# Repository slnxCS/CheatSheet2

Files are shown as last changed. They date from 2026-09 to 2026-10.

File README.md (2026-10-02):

# CheatSheet2

**[English](README.en.md)** · 🇷🇺 Русский

## О проекте

Портативное устройство на **ESP32-S3-N16R8 CAM** с цветным дисплеем, камерой и 5 кнопками управления

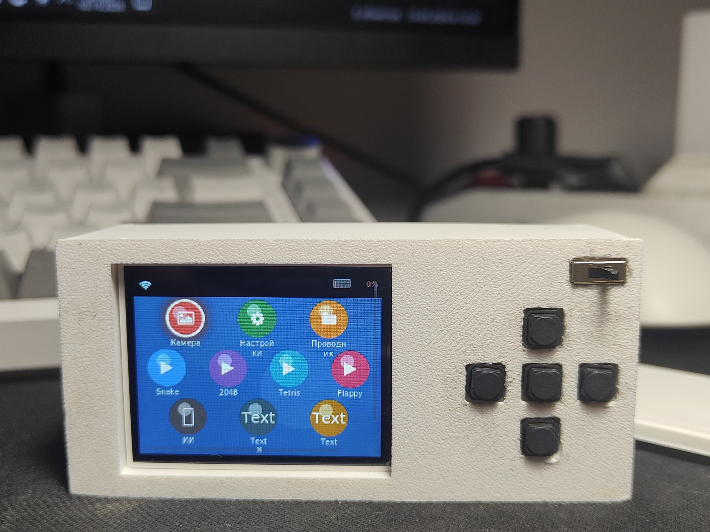
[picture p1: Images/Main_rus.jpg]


## ⚡ Возможности

 - Удобное управление с телефона с помощью приложения
 - Помещается в пенал
 - Бесшумные кнопки
 - Хорошо читаемый русский/английский текст
 - Много игр (Змейка, 2048, тетрис, flappy bird)
 - Большой дисплей
 - Камера
 - ИИ-агент (для работы нужно подключение с телефона), которому можно отправлять фото

## 🛠️ Сборка

### Необходимые компоненты

| Компонент | Кол-во | Ссылка для покупки (проверено для РФ) |
|---|:---:|---|
| ESP32-S3-CAM N16R8 (подойдёт любая камера, в проекте OV5640) | 1 | https://ali.click/lftxm1n |
| Любой аккумулятор | 1 | https://ozon.ru/t/T2QhKQN |
| TP4056 | 1 | https://ali.click/8ktxm18 |
| Бустер напряжения MT3608 | 1 | https://ali.click/9mtxm1z |
| TFT-дисплей 2.0" 320x240 ST7789 | 1 | https://ali.click/vntxm1e |
| Бесшумные кнопки | 3 | https://ali.click/fotxm1k |
| Тумблер питания | 1 | https://ali.click/crtxm11 |
| Резистор 10 кОм | 2 | https://ali.click/f9uxm1h |

## 🔌 Схема подключения

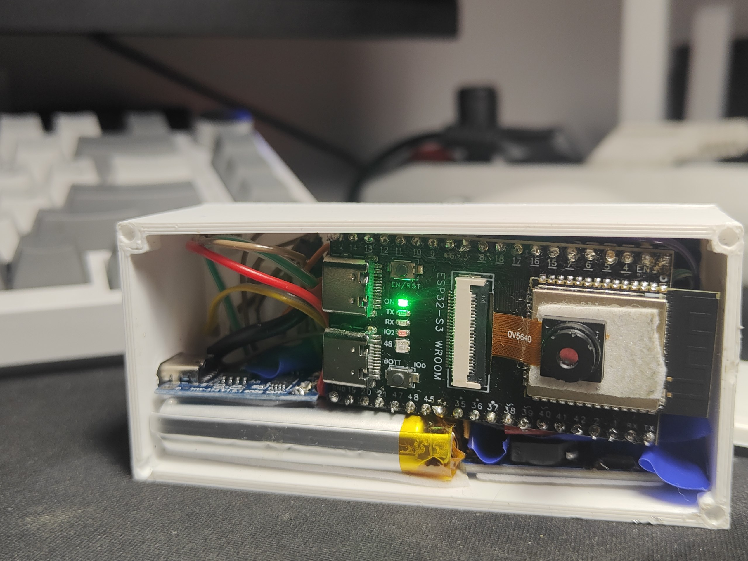
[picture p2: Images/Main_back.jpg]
BackView


| Модуль | Пин | Пин | Пин | Пин | Пин | Пин | Пин |
|---|-----|-----|-----|-----|-----|-----|-----|
| **🔋 Аккумулятор** | +(красный провод) → TP4056 bat + | -(чёрный провод) → TP4056 bat - | - | - | - | - | - |
| **🔋 TP4056** | Out + → центральная ножка переключателя (свитча) + | Out - → VIN - (повышайка напряжения MT3608) | Out + → резистор 10 кОм → ESP GPIO0 → резистор 10 кОм → ESP GND (-) | - | - | - | - |
| **Выключатель** | Правая ножка переключателя → VIN + (повышайка напряжения MT3608) | - | - | - | - | - | - |
| **MT3608 (бустер напряжения)** | VOUT(+) → ESP 5V | VOUT(-) → ESP GND | - | - | - | - | - |
| **Дисплей** | VCC(+) → ESP32 3.3V | GND(-) → ESP32 GND | SCLK (SCL) → ESP GPIO 41 | MOSI (SDA) → ESP GPIO 42 | CS → ESP GPIO 47 | DC → ESP GPIO 46 | RST → ESP32 3.3V |
| **Кнопки** (⚠️ 1 ножка каждой кнопки — на ESP GND) | Левая → GPIO 14 | Правая → GPIO 45 | Верхняя → GPIO 1 | Нижняя → GPIO 2 | OK → GPIO 21 | - | - |

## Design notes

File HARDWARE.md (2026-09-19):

# CheatSheet2 — Схема подключения

## Плата: ESP32-S3-N16R8 CAM (OV5640)

---

### Занятые GPIO (НЕЛЬЗЯ использовать)

```
┌────────────────────────────────────────────────────────┐
│ GPIO 0      — BOOT (strapping)                        │
│ GPIO 4-13   — Камера DVP (фирксована на плате)       │
│ GPIO 15-18  — Камера DVP                             │
│ GPIO 19-20  — USB D-/D+                               │
│ GPIO 26-32  — Flash SPI (internal)                    │
│ GPIO 33-37  — Octal PSRAM (8MB OPI)                  │
│ GPIO 38-40  — SD-карта (распаяна на плате)           │
│ GPIO 48     — WS2812 RGB LED (на некоторых платах)   │
└────────────────────────────────────────────────────────┘
```

---

### TFT 2.0" ST7789 240x320 (SPI)

```
┌─────────────────┐          ┌──────────────────────────┐
│   ST7789 TFT    │          │  ESP32-S3-N16R8 CAM      │
│                 │          │                          │
│  VCC  ──────────┼──────────┼── 3V3                    │
│  GND  ──────────┼──────────┼── GND                    │
│  MOSI ──────────┼──────────┼── GPIO 42                │
│  SCLK──────────┼──────────┼── GPIO 41                │
│  CS   ──────────┼──────────┼── GPIO 47                │
│  DC   ──────────┼──────────┼── GPIO 46                │
│  RST  ──────────┼── 3.3V   │  ( pull-up 10k к 3.3V ) │
│  BL   ──────────┼──────────┼── GPIO 45                │
│  MISO ──────────┼── (NC)   │  (не подключается)       │
└─────────────────┘          └──────────────────────────┘

ВАЖНО: RST не подключается к ESP32!
Подключите RST к 3.3V через подтягивающий резистор 10kОм.
Это освобождает GPIO для кнопок.
```

**Частота SPI**: 80 МГц
**Примечание**: MISO не используется — ST7789 только на запись

---

### Кнопки (5 шт, крестовина + OK)

```
┌───────────────┐          ┌──────────────────────────┐
│   Кнопка      │          │  ESP32-S3-N16R8 CAM      │
│               │          │                          │
│  UP    ───────┼──────────┼── GPIO 1  (P2 pin 4)    │
│  DOWN  ───────┼──────────┼── GPIO 2  (P2 pin 5)    │
│  LEFT  ───────┼──────────┼── GPIO 14 (P1 pin 19)   │
│  RIGHT ───────┼──────────┼── GPIO 3  (P1 pin 12)   │
│  OK    ───────┼──────────┼── GPIO 21 (P2 pin 18)   │
│               │          │                          │
│  Все GND ─────┼──────────┼── GND                    │
└───────────────┘          └──────────────────────────┘

Схема подключения одной кнопки:

    3.3V
     │
     ├── [Внутренний pull-up в ESP32]
     │
  GPIO ──────────────────┐
                         │
                    [КНОПКА]
                         │
                        GND

    Нажато:   GPIO = LOW  (0V)
    Отпущено: GPIO = HIGH (3.3V)
```

**Debounce**: 50 мс (программный)
**Long press**: 800 мс

---

### Камера OV5640 (DVP, припаяна к плате)

```
Камера OV5640 подключена через FPC коннектор на плате.
Все пины фиксированы, менять НЕЛЬЗЯ.

┌──────────────────┬─────────────────────────────┐
│ Сигнал OV5640    │ GPIO ESP32-S3               │
├──────────────────┼─────────────────────────────┤
│ XCLK             │ GPIO 15                     │
│ SIOD (SDA)       │ GPIO 4                      │
│ SIOC (SCL)       │ GPIO 5                      │
│ VSYNC            │ GPIO 6                      │
│ HREF             │ GPIO 7                      │
│ PCLK             │ GPIO 13                     │
│ D0 (Y2)          │ GPIO 11                     │
│ D1 (Y3)          │ GPIO 9                      │
│ D2 (Y4)          │ GPIO 8                      │
│ D3 (Y5)          │ GPIO 10                     │
│ D4 (Y6)          │ GPIO 12                     │
│ D5 (Y7)          │ GPIO 18                     │
│ D6 (Y8)          │ GPIO 17                     │
│ D7 (Y9)          │ GPIO 16                     │
│ PWDN             │ не подключён (-1)           │
│ RESET            │ не подключён (-1)           │
└──────────────────┴─────────────────────────────┘
```

---

### SD-карта (распаяна на плате)

```
SD-карта использует SPI шину и занимает 3 GPIO.
Пины подписаны на плате с символом "~" (meaning SD).

┌──────────────────┬─────────────────────────────┐
│ Сигнал SD        │ GPIO ESP32-S3               │
├──────────────────┼─────────────────────────────┤
│ CS               │ GPIO 38                     │
│ CLK              │ GPIO 39                     │
│ MOSI             │ GPIO 40                     │
└──────────────────┴─────────────────────────────┘

Эти GPIO заняты и НЕЛЬЗЯ использовать для других целей.
```

---

### Свободные GPIO (для будущего)

```
┌────────────────────────────────────────────────────────┐
│ Все свободные GPIO уже использованы:                   │
│ TFT: 41, 42, 45, 46, 47 (5 пинов)                    │
│ Кнопки: 1, 2, 21, 43, 44 (5 пинов)                   │
│ Итого: 10 GPIO заняты проектом                        │
└────────────────────────────────────────────────────────┘
```

---

### Питание

```
┌────────────────────────────────────────────────────────┐
│ USB Type-C 1  — UART дебаг (CH340/CP2102)             │
│ USB Type-C 2  — USB OTG (GPIO 19/20)                  │
│ 5V пин        — Вход питания от батареи/адаптера      │
│ 3V3 пин       — Выход стабилизатора 3.3V (макс 500мА)│
│                Вся логика работает на 3.3V             │
└────────────────────────────────────────────────────────┘

Потребление:
- Простой: ~100 мА
- Камера стриминг: ~350 мА
- Максимум (WiFi + камера + дисплей): ~500 мА
```

---

### Полная таблица пинов

| Разъём | GPIO | Функция в проекте | Статус |
|---|---|---|---|
| P2-4 | 1 | BTN_UP | Свободен |
| P2-5 | 2 | BTN_DOWN | Свободен |
| P1-13  | 3 | (не использовать) | Strapping |
| P1-3 | 4 | CAM_SDA | Камера |
| P1-4 | 5 | CAM_SCL | Камера |
| P1-5 | 6 | CAM_VSYNC | Камера |
| P1-6 | 7 | CAM_HREF | Камера |
| P1-11  | 8 | CAM_D2 | Камера |
| P1-14  | 9 | CAM_D1 | Камера |
| P1-15  | 10 | CAM_D3 | Камера |
| P1-16  | 11 | CAM_D0 | Камера |
| P1-17  | 12 | CAM_D4 | Камера |
| P1-18  | 13 | CAM_PCLK | Камера |
| P1-19  | 14 | (не использовать) | FSPIWP |
| P1-7 | 15 | CAM_XCLK | Камера |
| P1-8 | 16 | CAM_D7 | Камера |
| P1-9 | 17 | CAM_D6 | Камера |
| P1-10  | 18 | CAM_D5 | Камера |
| P2-19  | 19 | USB D- | USB |
| P2-18  | 20 | USB D+ | USB |
| P2-17  | 21 | BTN_OK | Кнопка |
| P2-9 | 38 | SD_CS | SD-карта |
| P2-8 | 39 | SD_CLK | SD-карта |
| P2-7 | 40 | SD_MOSI | SD-карта |
| P2-6 | 41 | TFT_SCLK | Дисплей |
| P2-5 | 42 | TFT_MOSI | Дисплей |
| P2-2 | 43 | BTN_LEFT | Кнопка |
| P2-1 | 44 | BTN_RIGHT | Кнопка |
| P2-14  | 45 | TFT_BL | Дисплей |
| P1-14  | 46 | TFT_DC | Дисплей |
| P1-17  | 47 | TFT_CS | Дисплей |
| P1-16  | 48 | (не использовать) | RGB LED? |

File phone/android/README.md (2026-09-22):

# CamLink — Android-приложение-мост для CheatSheet2

Цепочка работы:

1. Снимаете фото на устройстве (ESP32-S3-CAM).
2. Открываете CamLink на телефоне — приложение подключится к SoftAP
   устройства `CSCAM` (системный диалог «Подключиться» — один тап).
   **Интернет телефона не задействуется** — подключение локальное
   (`WifiNetworkSpecifier`), мобильный интернет остаётся дефолтным.
3. Жмёте «Спросить ИИ о последнем фото»:
   `GET /api/photo` → сжатие ≤1568px → API ИИ (Gemini/OpenAI, по ключу)
   → `POST /api/answer`.
4. Ответ текстом автоматически появляется на экране устройства
   (экран «ИИ» открывается сам).

## Сборка

Нужен Android Studio (или `./gradlew assembleDebug` при наличии SDK):

1. Android Studio → *Open* → папку `phone/android`.
2. Дождаться Gradle sync (скачает Gradle 8.7 + AGP 8.5; wrapper-jar
   Android Studio предложит создать — согласиться).
3. Run ▶ на телефоне (Android 10+, minSdk 29).

## Настройки (кнопка «⚙ Настройки»)

| Поле | Зачем |
|---|---|
| Провайдер ИИ | Google Gemini Flash или OpenAI GPT-4o-mini |
| API-ключ | Ключ выбранного провайдера (нужен баланс/бесплатный лимит) |
| Промпт | Что спрашивать ИИ (по умолчанию — «ответь кратко на вопрос с фото») |
| SSID/пароль | Сеть устройства (`CSCAM` / `cscam1234` по умолчанию) |

## HTTP API устройства (для отладки)

- `GET  http://192.168.4.1/api/state` — `{"state":…,"id":…,"name":…,"seq":…}`
- `GET  http://192.168.4.1/api/photo` — последнее фото (JPEG)
- `POST http://192.168.4.1/api/answer` — заголовок `X-Id`, тело — текст ответа
- `GET  http://192.168.4.1/` — страница с фото/ответом (отладка из браузера)

Внешних зависимостей нет — только системные Android API.

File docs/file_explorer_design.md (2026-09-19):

# File Explorer App — Design Spec

## Style
- Dark blue gradient background (#0A1628 → #0D47A1)
- Semi-transparent panel cards (rgba(13,71,161, 0.4), radius 12)
- White text, muted text (#80CBC4 accent teal)
- Fonts: lv_font_cyr_14 (titles), lv_font_cyr_12 (items), lv_font_cyr_10 (hints)
- PS Vita LiveArea aesthetic: rounded cards, clean spacing, minimal borders

## Layout (320x240)
```
┌──────────────────────────────────────┐
│ 📁 Проводник          [Flash] [SD]   │  32px header
├──────────────────────────────────────┤
│ /path/to/current/dir                 │  20px breadcrumb
├──────────────────────────────────────┤
│ 📁 ..                                │
│ 📁 photos                           │
│ 📄 readme.txt          1.2 KB       │  scrollable list
│ 🖼 photo.jpg           245 KB       │
│ 🔧 config.json         0.5 KB       │
│                                      │
├──────────────────────────────────────┤
│ ▲▼ select  ◄► open/back  ◄► source  │  16px hint bar
└──────────────────────────────────────┘
```

## Navigation
- UP/DOWN: scroll through file list
- LEFT: go back (parent directory), if at root → show source picker
- RIGHT: enter directory / open file info
- Long OK: exit app

## Source Selection
- At root level, LEFT cycles between Internal Flash and SD Card
- Sources shown as tabs in header, active one highlighted in teal
- If SD card not mounted, show error message

## File Icons
- Folder: LV_SYMBOL_DIRECTORY (📁)
- .txt/.log/.csv/.json/.xml: LV_SYMBOL_FILE (📄)
- .jpg/.jpeg/.png/.bmp/.gif: LV_SYMBOL_IMAGE (🖼)
- .mp3/.wav/.ogg: LV_SYMBOL_AUDIO (🔊)
- .mp4/.avi/.mov: LV_SYMBOL_VIDEO (🎬)
- Unknown: LV_SYMBOL_EDIT (🔧)
- Parent (..): LV_SYMBOL_PREV (◀)

## File Info
- Directories show item count "N files"
- Files show human-readable size (B, KB, MB)

## Filesystem Support
- Internal: LittleFS (/littlefs mount point)
- SD: SD_MMC 1-bit mode (GPIO 38/39/40, 20MHz)
- Both use POSIX-like API (File class)

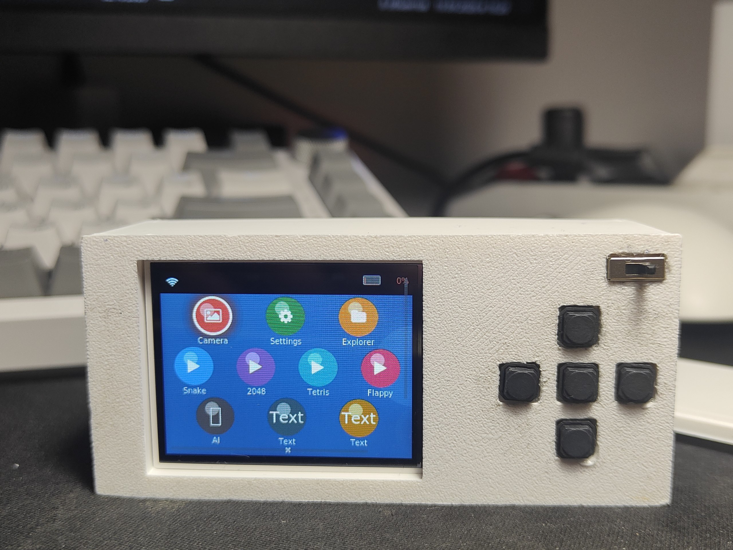
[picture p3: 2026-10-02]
Images/Main_eng.jpg

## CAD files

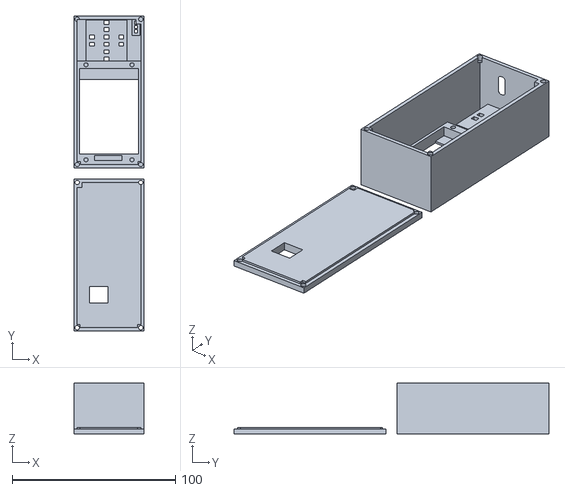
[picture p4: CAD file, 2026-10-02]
Case3DModel/CheatSheat2Case.stl
43.0 x 193.0 x 31.0

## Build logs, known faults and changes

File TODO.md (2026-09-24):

# CheatSheet2 — TODO

## Hardware
- [x] ESP32-S3-N16R8 CAM + OV5640
- [x] TFT 2.0" 240x320 ST7789 (SPI)
- [x] 5 кнопок (крестовина + OK)
- [x] WiFi связь с телефоном

## Распиновка
- [x] TFT: MOSI=42, SCLK=41, CS=40, DC=39, RST=47, BL=46
- [x] Кнопки: UP=1, DOWN=2, LEFT=38, RIGHT=21, OK=43
- [x] Камера: XCLK=15, SDA=4, SCL=5, VSYNC=6, HREF=7, PCLK=13, D0-D7=11,9,8,10,12,18,17,16

## Задачи

### Phase 1: Основа (MVP)
- [x] platformio.ini
- [x] pins.h
- [x] lv_conf.h (LVGL 9.x, шрифты 10-24, все виджеты)
- [x] display driver (TFT_eSPI + LVGL flush, DMA, PSRAM буферы)
- [x] input driver (кнопки + debounce + long press)
- [x] splash screen (анимация загрузки)
- [x] status bar (WiFi, время)
- [x] home screen (PS Vita style, круглые иконки, сетка 3x2)
- [x] theme (тёмная тема, палитра PS Vita)
- [x] ui manager (переключение экранов)
- [x] main.cpp (init + loop + button navigation)

### Phase 2: Приложения
- [x] app base class + registry (макс 8 приложений)
- [x] camera driver (OV5640, JPEG, PSRAM)
- [x] camera app (просмотр + авто-обновление)
- [x] settings app (яркость слайдер)
- [x] WiFi service (HTTP server для связи с телефоном)
- [x] WiFi transfer app (отправка JPEG на телефон)
- [x] ai_link (SoftAP «CSCAM» + HTTP: фото → телефон, ответ ИИ → экран)
- [x] Android-приложение-мост (клавиатура → вопрос, фото → ИИ, ответ в чат)
- [x] Чат на устройстве (экран «ИИ»: пузыри, история в LittleFS)

### Phase 3: Polish
- [ ] OTA service
- [ ] Кастомные шрифты
- [ ] Иконки (PNG → C массивы)
- [ ] Анимации переходов
- [ ] Энергосбережение (auto-sleep)

## Архитектура
```
src/
├── main.cpp
├── drivers/         (display, camera, input)
├── ui/              (screens, widgets, theme)
├── apps/            (builtin apps + registry)
└── services/        (wifi, ota)
```

## Библиотеки
- LVGL 9.6.0
- TFT_eSPI 2.5.43
- esp32-camera (встроенная)
- WiFi (встроенная)

## Статус сборки
- RAM:   40.9% (134040 / 327680 bytes)
- Flash: 53.1% (1390969 / 2621440 bytes)

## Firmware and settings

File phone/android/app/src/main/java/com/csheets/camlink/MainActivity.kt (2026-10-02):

package com.csheets.camlink

import android.app.Activity
import android.app.AlertDialog
import android.content.ContentValues
import android.content.Context
import android.content.Intent
import android.net.Uri
import android.net.wifi.WifiManager
import android.os.Bundle
import android.os.Environment
import android.os.Handler
import android.os.Looper
import android.os.PowerManager
import android.provider.OpenableColumns
import android.provider.Settings
import android.provider.MediaStore
import android.text.InputType
import android.util.TypedValue
import android.view.View
import android.widget.Button
import android.widget.EditText
import android.widget.LinearLayout
import android.widget.ScrollView
import android.widget.Spinner
import android.widget.ArrayAdapter
import android.widget.ListView
import android.widget.TextView
import org.json.JSONArray
import java.io.IOException
import java.net.URLEncoder
import java.util.concurrent.Executors
import kotlin.concurrent.thread

/*
 * CamLink — посредник «телефон ⇄ устройство CheatSheet2 ⇄ ИИ».
 *
 * Сам чат живёт на УСТРОЙСТВЕ (экран «ИИ»). Телефон только:
 *   1) принимает текст с клавиатуры и фото (устройство / галерея),
 *   2) немедленно шлёт вопрос на устройство (POST /api/question),
 *   3) спрашивает ИИ через мобильный интернет,
 *   4) доставляет ответ (POST /api/answer) — он дописывается в вопрос.
 *
 * Подключение: WifiNetworkSpecifier (Android 10+) — локальная сеть к SoftAP
 * «CSCAM», мобильный интернет остаётся для API ИИ.
 *
 * Вся рабочая логика (сеть, опрос /api/state, вызовы ИИ) живёт в
 * BridgeService — foreground-сервисе, который переживает уход приложения
 * в фон и погашение экрана. Activity здесь только рисует и подписывается
 * на журнал через BridgeBus.
 */
class MainActivity : Activity() {

    private lateinit var tvStatus: TextView
    private lateinit var tvLog: TextView
    private lateinit var etInput: EditText
    private lateinit var btnSend: Button
    private lateinit var btnQuick: Button
    private val mainHandler = Handler(Looper.getMainLooper())
    private val exec = Executors.newSingleThreadExecutor()

    private val prefs by lazy { getSharedPreferences("camlink", Context.MODE_PRIVATE) }

    // ---------- Жизненный цикл ----------

    override fun onCreate(savedInstanceState: Bundle?) {
        super.onCreate(savedInstanceState)
        buildUi()
        attachBus()
        maybePromptWifi()
        maybeAskBattery()
        startForegroundService(Intent(this, BridgeService::class.java))
        // Если прошлый старт сервиса не смог показать системный диалог
        // подключения (приложение было в фоне) — повторяем, пока мы на виду.
        BridgeService.instance?.ensureConnected()
    }

    override fun onDestroy() {
        BridgeBus.onLog = null
        BridgeBus.onStatus = null
        BridgeBus.onLink = null
        BridgeBus.onSendDone = null
        BridgeBus.onAskDone = null
        exec.shutdownNow()
        super.onDestroy()
    }

    // Подписка на журнал моста: реплей истории + живые обновления
    private fun attachBus() {
        BridgeBus.onLog = { line -> mainHandler.post { appendLog(line) } }
        BridgeBus.onStatus = { s -> mainHandler.post { tvStatus.text = s } }
        BridgeBus.onLink = { linked -> mainHandler.post { btnQuick.isEnabled = linked } }
        BridgeBus.onSendDone = { mainHandler.post { btnSend.isEnabled = true } }
        BridgeBus.onAskDone = { mainHandler.post { btnQuick.isEnabled = BridgeBus.linked } }
        BridgeBus.replay().forEach { appendLog(it) }
        if (BridgeBus.lastStatus.isNotEmpty()) tvStatus.text = BridgeBus.lastStatus
        btnQuick.isEnabled = BridgeBus.linked
    }

    private fun appendLog(msg: String) {
        tvLog.append(msg + "\n")
        (tvLog.parent as? ScrollView)?.post {
            (tvLog.parent as ScrollView).fullScroll(View.FOCUS_DOWN)
        }
    }

    @Suppress("DEPRECATION")
    private fun maybePromptWifi() {
        val wifi = applicationContext.getSystemService(Context.WIFI_SERVICE) as WifiManager
        if (!wifi.isWifiEnabled) {
            status("WiFi выключен — включаю настройки")
            try { startActivity(Intent(Settings.ACTION_WIFI_SETTINGS)) } catch (_: Exception) {}
            log("! Включите WiFi и вернитесь в приложение (кнопка ↻)")
        }
    }

    // Android режет сеть фоновым приложениям (Doze) — просим исключение,
    // иначе с выключенным экраном связь с устройством будет обрываться.
    private fun maybeAskBattery() {
        if (prefs.getBoolean("battAsked", false)) return
        val pm = getSystemService(Context.POWER_SERVICE) as PowerManager
        if (pm.isIgnoringBatteryOptimizations(packageName)) return
        prefs.edit().putBoolean("battAsked", true).apply()
        log("! Разрешите CamLink работать без ограничений батареи —")
        log("  иначе Android усыпит связь в фоне (экран погас)")
        try {
            startActivity(Intent(Settings.ACTION_REQUEST_IGNORE_BATTERY_OPTIMIZATIONS,
                Uri.parse("package:$packageName")))
        } catch (e: Exception) {
            log("  не удалось: ${e.message} — вручную: Настройки → Батарея → Исключения")
        }
    }

    // ---------- Интерфейс (программный, без XML) ----------

    private fun dp(v: Int): Int =
        TypedValue.applyDimension(TypedValue.COMPLEX_UNIT_DIP, v.toFloat(),
            resources.displayMetrics).toInt()

    private fun buildUi() {
        val root = LinearLayout(this).apply {
            orientation = LinearLayout.VERTICAL
            setPadding(dp(12), dp(10), dp(12), dp(10))
        }

        root.addView(TextView(this).apply {
            text = "🔗 CamLink — мост к ИИ"
            textSize = 18f
            setPadding(0, 0, 0, dp(2))
        })

        tvStatus = TextView(this).apply {
            text = "Подключение к CSCAM…"
            textSize = 13f
            setTextColor(0xFF8FA3BF.toInt())
            setPadding(0, 0, 0, dp(6))
        }
        root.addView(tvStatus)

        // Клавиатура телефона → вопрос на устройство → ответ ИИ обратно
        val inputRow = LinearLayout(this).apply { orientation = LinearLayout.HORIZONTAL }
        val btnAttach = Button(this).apply {
            text = "📎"
            setOnClickListener { attachMenu() }
        }
        inputRow.addView(btnAttach, LinearLayout.LayoutParams(
            LinearLayout.LayoutParams.WRAP_CONTENT, LinearLayout.LayoutParams.WRAP_CONTENT, 0f))
        etInput = EditText(this).apply {
            hint = "Вопрос для ИИ…"
            maxLines = 3
            inputType = InputType.TYPE_CLASS_TEXT or InputType.TYPE_TEXT_FLAG_MULTI_LINE
        }
        inputRow.addView(etInput, LinearLayout.LayoutParams(
            0, LinearLayout.LayoutParams.WRAP_CONTENT, 1f))
        btnSend = Button(this).apply {
            text = "→"
            setOnClickListener { send() }
        }
        inputRow.addView(btnSend, LinearLayout.LayoutParams(
            LinearLayout.LayoutParams.WRAP_CONTENT, LinearLayout.LayoutParams.WRAP_CONTENT, 0f))
        root.addView(inputRow, LinearLayout.LayoutParams(
            LinearLayout.LayoutParams.MATCH_PARENT, LinearLayout.LayoutParams.WRAP_CONTENT))

        val actionRow = LinearLayout(this).apply { orientation = LinearLayout.HORIZONTAL }
        btnQuick = Button(this).apply {
            text = "📷 Спросить о фото"
            textSize = 13f
            isEnabled = false
            setOnClickListener { quickAsk() }
        }
        actionRow.addView(btnQuick, LinearLayout.LayoutParams(
            0, LinearLayout.LayoutParams.WRAP_CONTENT, 1f))
        actionRow.addView(Button(this).apply {
            text = "⚙"
            setOnClickListener { openSettings() }
        }, LinearLayout.LayoutParams(LinearLayout.LayoutParams.WRAP_CONTENT,
            LinearLayout.LayoutParams.WRAP_CONTENT, 0f))
        actionRow.addView(Button(this).apply {
            text = "📁"
            setOnClickListener {
                startActivity(Intent(this@MainActivity, FileActivity::class.java))
            }
        }, LinearLayout.LayoutParams(LinearLayout.LayoutParams.WRAP_CONTENT,
            LinearLayout.LayoutParams.WRAP_CONTENT, 0f))
        actionRow.addView(Button(this).apply {
            text = "↻"
            setOnClickListener { BridgeService.reconnect() }
        }, LinearLayout.LayoutParams(LinearLayout.LayoutParams.WRAP_CONTENT,
            LinearLayout.LayoutParams.WRAP_CONTENT, 0f))
        root.addView(actionRow, LinearLayout.LayoutParams(
            LinearLayout.LayoutParams.MATCH_PARENT, LinearLayout.LayoutParams.WRAP_CONTENT))

        val scroll = ScrollView(this).apply {
            layoutParams = LinearLayout.LayoutParams(
                LinearLayout.LayoutParams.MATCH_PARENT, 0, 1f)
        }
        tvLog = TextView(this).apply {
            textSize = 13f
            typeface = android.graphics.Typeface.MONOSPACE
        }
        scroll.addView(tvLog)
        root.addView(scroll)

        setContentView(root)
    }

    private fun log(msg: String) = BridgeBus.log(msg)

    private fun status(msg: String) = BridgeBus.status(msg)

    // ---------- Отправка (работа выполняется в BridgeService) ----------

    // Текст (± фото) → вопрос сразу на устройство → ИИ → ответ на устройство
    private fun send() {
        val text = etInput.text.toString().trim()
        val photo = pendingPhoto
        if (text.isEmpty() && photo == null) return
        etInput.setText("")
        btnSend.isEnabled = false
        if (!BridgeService.submitQuestion(text, photo)) {
            log("! Мост ещё не запущен — попробуйте через секунду")
            btnSend.isEnabled = true
        }
    }

    private fun quickAsk() {
        btnQuick.isEnabled = false
        if (!BridgeService.photoAsk()) {
            log("! Мост ещё не запущен — попробуйте через секунду")
            btnQuick.isEnabled = BridgeBus.linked
        }
    }

    // ---------- Прикрепление фото ----------

    private fun attachMenu() {
        AlertDialog.Builder(this)
            .setTitle("Прикрепить фото")
            .setItems(arrayOf("Фото с устройства", "Фото из галереи")) { _, which ->
                if (which == 0) attachFromDevice() else pickFromGallery()
            }
            .setNegativeButton("Отмена", null)
            .show()
    }

    private fun attachFromDevice() {
        exec.execute {
            try {
                val (pcode, photo) = espRequest("/api/photo")
                if (pcode != 200 || photo.isEmpty())
                    throw IOException("нет фото на устройстве (HTTP $pcode)")
                pendingPhoto = photo
                log("📎 Фото с устройства прикреплено (${photo.size / 1024} КБ)")
                status("Фото прикреплено — введите вопрос")
            } catch (e: Exception) {
                status(e.message ?: "Ошибка")
            }
        }
    }

    private fun pickFromGallery() {
        val intent = Intent(Intent.ACTION_GET_CONTENT)
            .addCategory(Intent.CATEGORY_OPENABLE)
            .setType("image/*")
        startActivityForResult(intent, 100)
    }

    override fun onActivityResult(requestCode: Int, resultCode: Int, data: Intent?) {
        super.onActivityResult(requestCode, resultCode, data)
        if (requestCode != 100 || resultCode != RESULT_OK) return
        val uri = data?.data ?: return
        thread {
            try {
                val bytes = contentResolver.openInputStream(uri)?.use { it.readBytes() }
                    ?: throw IOException("не удалось прочитать фото")
                pendingPhoto = bytes
                log("📎 Фото из галереи прикреплено (${bytes.size / 1024} КБ)")
                status("Фото прикреплено — введите вопрос")
            } catch (e: Exception) {
                status(e.message ?: "Ошибка")
            }
        }.start()
    }

    // ---------- Настройки ----------

    private fun openSettings() {
        val layout = LinearLayout(this).apply {
            orientation = LinearLayout.VERTICAL
            setPadding(dp(24), dp(8), dp(24), 0)
        }

        layout.addView(TextView(this).apply { text = "Провайдер ИИ" })
        val spinner = Spinner(this).apply {
            adapter = ArrayAdapter(context,
                android.R.layout.simple_spinner_dropdown_item,
                listOf("Google Gemini Flash (бесплатный)",
                       "OpenAI GPT-4o-mini",
                       "OpenRouter (бесплатные модели)"))
            setSelection(when (prefs.getString("provider", "gemini")) {
                "openai" -> 1
                "openrouter" -> 2
                else -> 0
            })
        }
        layout.addView(spinner)

        val keyEdit = EditText(this).apply {
            hint = "API-ключ"
            inputType = InputType.TYPE_CLASS_TEXT or InputType.TYPE_TEXT_VARIATION_PASSWORD
            setText(prefs.getString("key", ""))
        }
        layout.addView(keyEdit)

        layout.addView(TextView(this).apply {
            text = "Модель"; setPadding(0, dp(12), 0, 0)
        })
        val modelEdit = EditText(this).apply {
            hint = "пусто = по умолчанию (gemini-3.6-flash / " +
                   "gpt-4o-mini / openrouter/free)"
            setText(prefs.getString("model", ""))
        }
        layout.addView(modelEdit)

        layout.addView(TextView(this).apply {
            text = "Прокси для ИИ (порт Happ при активном VPN)"
            setPadding(0, dp(12), 0, 0)
        })
        val proxyEdit = EditText(this).apply {
            hint = "127.0.0.1:10809 или socks5://127.0.0.1:10808 — пусто = напрямую"
            setText(prefs.getString("ai_proxy", ""))
        }
        layout.addView(proxyEdit)

        layout.addView(TextView(this).apply {
            text = "Промпт (для фото)"
            setPadding(0, dp(12), 0, 0)
        })
        val promptEdit = EditText(this).apply {
            hint = "Что спрашивать у ИИ по фото"
            inputType = InputType.TYPE_CLASS_TEXT or InputType.TYPE_TEXT_FLAG_MULTI_LINE
            minLines = 3
            setText(prefs.getString("prompt", DEFAULT_PROMPT))
        }
        layout.addView(promptEdit)

        layout.addView(TextView(this).apply {
            text = "Сеть устройства (SSID / пароль)"; setPadding(0, dp(12), 0, 0)
        })
        val ssidEdit = EditText(this).apply {
            hint = "SSID"
            setText(prefs.getString("ssid", "CSCAM"))
        }
        layout.addView(ssidEdit)
        val passEdit = EditText(this).apply {
            hint = "Пароль"
            inputType = InputType.TYPE_CLASS_TEXT or InputType.TYPE_TEXT_VARIATION_PASSWORD
            setText(prefs.getString("pass", "cscam1234"))
        }
        layout.addView(passEdit)

        val scroll = ScrollView(this).apply { addView(layout) }

        AlertDialog.Builder(this)
            .setTitle("Настройки CamLink")
            .setView(scroll)
            .setPositiveButton("Сохранить") { _, _ ->
                prefs.edit()
                    .putString("provider", when (spinner.selectedItemPosition) {
                        1 -> "openai"
                        2 -> "openrouter"
                        else -> "gemini"
                    })
                    .putString("key", keyEdit.text.toString().trim())
                    .putString("model", modelEdit.text.toString().trim())
                    .putString("ai_proxy", proxyEdit.text.toString().trim())
                    .putString("prompt", promptEdit.text.toString().trim())
                    .putString("ssid", ssidEdit.text.toString().trim())
                    .putString("pass", passEdit.text.toString().trim())
                    .apply()
                log("Настройки сохранены")
            }
            .setNegativeButton("Отмена", null)
            .show()
    }
}

// ---------- Файлы устройства (📁): флэш LittleFS и SD-карта ----------
// API: GET /api/fs — список, GET /api/file — скачать,
// POST /api/file — загрузить (потоково), DELETE — удалить.
// Виртуальные пути устройства: "/flash/..." → LittleFS, "/sd/..." → SD.
private data class FsEntry(val name: String, val dir: Boolean, val size: Long)
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

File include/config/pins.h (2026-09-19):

#pragma once

// ============================================================
// CheatSheet2 Pin Definitions
// ESP32-S3-N16R8 CAM + ST7789 240x320 + 5 кнопок
//
// SD-карта на плате занимает: GPIO 38, 39, 40
// RST дисплея: tied to 3.3V ( pull-up 10k )
// ============================================================

// --- TFT Display (ST7789, HSPI через GPIO matrix) ---
// RST не подключён к GPIO — напрямую на 3.3V через 10k pull-up
#define PIN_TFT_MOSI    42
#define PIN_TFT_SCLK    41
#define PIN_TFT_CS      47
#define PIN_TFT_DC      46
#define PIN_TFT_BL      -1

// --- Кнопки (к GND, internal pull-up) ---
#define PIN_BTN_UP       1
#define PIN_BTN_DOWN     2
#define PIN_BTN_LEFT    14
#define PIN_BTN_RIGHT   45
#define PIN_BTN_OK      21

// --- Камера OV5640 (DVP, фиксирована на плате) ---
#define PIN_CAM_XCLK    15
#define PIN_CAM_SDA      4
#define PIN_CAM_SCL      5
#define PIN_CAM_VSYNC    6
#define PIN_CAM_HREF     7
#define PIN_CAM_PCLK    13
#define PIN_CAM_D0      11
#define PIN_CAM_D1       9
#define PIN_CAM_D2       8
#define PIN_CAM_D3      10
#define PIN_CAM_D4      12
#define PIN_CAM_D5      18
#define PIN_CAM_D6      17
#define PIN_CAM_D7      16

// --- SD-карта (распаяна на плате, НЕЛЬЗЯ использовать) ---
// GPIO 38 = SD_CS
// GPIO 39 = SD_CLK
// GPIO 40 = SD_MOSI

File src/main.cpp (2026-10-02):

#include <Arduino.h>
#include <esp_system.h>
#include "config/pins.h"
#include "drivers/display.h"
#include "drivers/input.h"
#include "ui/ui_manager.h"
#include "ui/screens/home_screen.h"
#include "apps/app_registry.h"
#include "apps/app_base.h"
#include "apps/builtin/camera_app.h"
#include "apps/builtin/settings_app.h"
#include "apps/builtin/file_explorer_app.h"
#include "apps/builtin/snake_game.h"
#include "apps/builtin/game_2048.h"
#include "apps/builtin/tetris_game.h"
#include "apps/builtin/flappy_game.h"
#include "apps/builtin/ai_answer_app.h"
#include "services/lang_service.h"
#include "services/storage_service.h"
#include "services/battery_service.h"
#include "services/wifi_service.h"
#include "services/time_service.h"
#include "services/ai_link.h"
#include "ui/app_host.h"
#include "ui/theme.h"
#include "SD_MMC.h"
#include "LittleFS.h"

static bool in_app = false;
static int current_app_idx = -1;
static int ai_app_idx = -1;

static void init_fs() {
    storage_set_constrain(LittleFS.begin(true) ? 0 : -1);

    SD_MMC.setPins(39,38,40);
    storage_set_constrain(SD_MMC.begin("/sdcard", true) ? 1 : 0);
}

static void host_open(int idx) {
    current_app_idx = idx;
    in_app = true;
    ui_manager_switch(SCREEN_APP);
    app_registry_open(idx, lv_screen_active());
}

static void host_close_to_home() {
    app_registry_close(current_app_idx);
    in_app = false;
    current_app_idx = -1;
    ui_manager_reload_home();
}

// --- app_host: программное открытие (ai_link → экран «ИИ») ---

void app_host_open_index(int idx) {
    if (idx < 0 || idx >= app_registry_count()) return;
    if (in_app) {
        if (current_app_idx == idx) return;
        // Переключение: закрыть текущее приложение без возврата на домой
        app_registry_close(current_app_idx);
        current_app_idx = -1;
        in_app = false;
    }
    host_open(idx);
}

bool app_host_in_app() { return in_app; }
int  app_host_current() { return current_app_idx; }
int  app_host_ai_index() { return ai_app_idx; }

static void on_button(ButtonId id, ButtonEvent event) {
    if (in_app) {
        if (id == BTN_ID_OK && event == BTN_EVENT_LONG_PRESSED) {
            host_close_to_home();
            return;
        }
        // PRESSED и LONG_PRESSED тоже пробрасываем: PRESSED — игры (Flappy)
        // реагируют на нажатие, LONG (кроме OK — он выходит из приложения) —
        // переключение режима превью в камере. Остальные приложения
        // фильтруют по BTN_EVENT_CLICKED.
        if (event == BTN_EVENT_CLICKED || event == BTN_EVENT_PRESSED ||
            event == BTN_EVENT_LONG_PRESSED) {
            AppContext* app = app_registry_get_running();
            if (app && app->on_button) {
                app->on_button((int)id, (int)event);
            }
        }
        return;
    }

    if (event != BTN_EVENT_CLICKED) return;

    int selected = home_screen_get_selected();
    int count = home_screen_get_app_count();
    if (count == 0) return;

    int cols = APP_GRID_COLS;

    switch (id) {
        case BTN_ID_UP:
            if (selected >= cols) selected -= cols;
            break;
        case BTN_ID_DOWN:
            if (selected + cols < count) selected += cols;
            break;
        case BTN_ID_LEFT:
            if (selected > 0) selected--;
            break;
        case BTN_ID_RIGHT:
            if (selected < count - 1) selected++;
            break;
        case BTN_ID_OK:
            host_open(selected);
            return;
        default:
            break;
    }

    home_screen_set_selected(selected);
}

void setup() {
    Serial.begin(115200);
    delay(1000);

    Serial.println("=== CheatSheet2 ===");
    // Причина рестарта: 3=panic, 4=кормление WDT, 9=питание — ловим вылеты
    Serial.printf("Reset reason: %d\n", (int)esp_reset_reason());
    Serial.printf("CPU freq: %d MHz\n", getCpuFrequencyMhz());
    Serial.printf("Free heap: %u bytes\n", (unsigned)ESP.getFreeHeap());

    if (psramFound()) {
        Serial.printf("PSRAM: %u bytes free\n", (unsigned)ESP.getFreePsram());
    } else {
        Serial.println("WARNING: PSRAM not found!");
    }

    Serial.println("[1/6] Display...");
    display_init();
    Serial.println("[1/6] Display DONE");

    Serial.println("[2.7/6] Battery...");
    battery_init();

    Serial.println("[2/6] Input...");
    input_init();
    input_set_callback(on_button);
    Serial.println("[2/6] Input DONE");

    Serial.println("[2.5/6] Language...");
    lang_init();
    Serial.printf("[2.5/6] Language: %d\n", lang_get());

    Serial.println("[2.6/6] Storage...");
    storage_init();
    Serial.printf("[2.6/6] Storage: %d\n", storage_get());

    Serial.println("[3/6] Apps...");
    app_registry_init();
    app_registry_add(lang_str_app_camera(),  LV_SYMBOL_IMAGE,  camera_app_open,  camera_app_close, camera_app_button);
    app_registry_add(lang_str_app_settings(), LV_SYMBOL_SETTINGS, settings_app_open, settings_app_close, settings_app_button);
    app_registry_add(lang_str_app_explorer(), LV_SYMBOL_DIRECTORY, file_explorer_open, file_explorer_close, file_explorer_button);
    app_registry_add("Snake", LV_SYMBOL_PLAY, snake_game_open, snake_game_close, snake_game_button);
    app_registry_add("2048", LV_SYMBOL_PLAY, game_2048_open, game_2048_close, game_2048_button);
    app_registry_add("Tetris", LV_SYMBOL_PLAY, tetris_game_open, tetris_game_close, tetris_game_button);
    app_registry_add("Flappy", LV_SYMBOL_PLAY, flappy_game_open, flappy_game_close, flappy_game_button);
    ai_app_idx = app_registry_add(lang_str_app_ai(), LV_SYMBOL_EDIT,
                                  ai_answer_app_open, ai_answer_app_close,
                                  ai_answer_app_button);
    Serial.printf("[3/6] Apps registered: %d\n", app_registry_count());

    Serial.println("[4/6] UI...");
    ui_manager_init();
    Serial.println("[4/6] UI DONE");

    Serial.println("[5/6] Registering apps on home...");
    for (int i = 0; i < app_registry_count() && i < APP_GRID_COLS * APP_GRID_ROWS; i++) {
        AppContext* app = app_registry_get(i);
        if (app) {
            home_screen_register_app(app->name, app->icon_symbol, nullptr);
        }
    }
    Serial.println("[5/6] Apps registered on home");

    Serial.println("[6/6] Boot complete!");

    init_fs();
    time_service_boot_restore();   // /clock → время переживает ребут

    // WiFi SoftAP («CSCAM») + HTTP-мост «устройство → телефон → ИИ».
    // Порядок важен: сначала WiFi (init может ничего не запустить, если
    // выключен в настройках), затем ai_link — сервер начнётся только
    // при реально поднятом AP (см. ai_link_ensure_server).
    Serial.println("[7/7] WiFi + AI link...");
    wifi_service_init();
    ai_link_init();
    Serial.println("[7/7] WiFi + AI link DONE");
}

static unsigned long last_tick = 0;
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

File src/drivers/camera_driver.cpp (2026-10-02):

#include "drivers/camera_driver.h"
#include "config/pins.h"
#include <Arduino.h>

#ifdef BOARD_HAS_PSRAM
#include "esp_camera.h"

// OV5640 VCM (Voice Coil Motor) focus registers
#define OV5640_MODULE_ID_ADDR   0x3000
#define OV5640_SC_PRE_BIAS_ADDR 0x5218
#define OV5640_SC_MAST_BIAS_ADDR 0x5217
#define OV5640_SC_LINE_ADDR     0x5216
#define OV5640_SC_STEP_ADDR     0x5215

static bool cam_ready = false;
static camera_fb_t* current_fb = nullptr;
static int current_focus = 512;

// Запись в регистр через SCCB (I2C камеры)
static void ov5640_write_reg(uint16_t reg, uint8_t val) {
    sensor_t* s = esp_camera_sensor_get();
    if (s) s->set_reg(s, reg, 0xFF, val);
}

static void ov5640_set_focus(int pos) {
    // OV5640 VCM control: разбиваем позицию на 3 регистра
    uint8_t h = (pos >> 8) & 0x03;
    uint8_t m = (pos >> 4) & 0x0F;
    uint8_t l = pos & 0x0F;

    ov5640_write_reg(0x5218, (h << 4) | l);  // SC_PRE_BIAS
    ov5640_write_reg(0x5217, m);              // SC_MAST_BIAS
    ov5640_write_reg(0x5216, 0x01);           // SC_LINE = 1 (manual mode)
    ov5640_write_reg(0x5215, 0x01);           // SC_STEP = 1 (enable direct control)

    Serial.printf("Focus set: %d\n", pos);
}

bool camera_init() {
    if (cam_ready) return true;   // уже «тёплая» (см. camera_app_warm_poll):
                                  // повторный esp_camera_init = паника
    camera_config_t config = {};
    config.ledc_channel = LEDC_CHANNEL_0;
    config.ledc_timer = LEDC_TIMER_0;
    config.pin_d0 = PIN_CAM_D0;
    config.pin_d1 = PIN_CAM_D1;
    config.pin_d2 = PIN_CAM_D2;
    config.pin_d3 = PIN_CAM_D3;
    config.pin_d4 = PIN_CAM_D4;
    config.pin_d5 = PIN_CAM_D5;
    config.pin_d6 = PIN_CAM_D6;
    config.pin_d7 = PIN_CAM_D7;
    config.pin_xclk = PIN_CAM_XCLK;
    config.pin_pclk = PIN_CAM_PCLK;
    config.pin_vsync = PIN_CAM_VSYNC;
    config.pin_href = PIN_CAM_HREF;
    config.pin_sccb_sda = PIN_CAM_SDA;
    config.pin_sccb_scl = PIN_CAM_SCL;
    config.pin_pwdn = -1;
    config.pin_reset = -1;
    config.xclk_freq_hz = 20000000;
    config.pixel_format = PIXFORMAT_JPEG;

    if (psramFound()) {
        config.frame_size = FRAMESIZE_UXGA;  // 1600x1200
        config.jpeg_quality = 4;              // 0-63, меньше = качественнее: мелкий текст детальнее
        config.fb_count = 2;
        config.grab_mode = CAMERA_GRAB_LATEST;
        config.fb_location = CAMERA_FB_IN_PSRAM;
    } else {
        config.frame_size = FRAMESIZE_VGA;
        config.fb_location = CAMERA_FB_IN_DRAM;
        config.fb_count = 1;
    }

    esp_err_t err = esp_camera_init(&config);
    if (err != ESP_OK) {
        Serial.printf("Camera init failed: 0x%x\n", err);
        cam_ready = false;
        return false;
    }

    sensor_t* s = esp_camera_sensor_get();
    if (s) {
        s->set_brightness(s, 0);
        s->set_saturation(s, -1);
        s->set_contrast(s, 2);     // чётче разделение «чернила/бумага» (диапазон −3..3)
        s->set_sharpness(s, 3);    // максимум (−3..3): резче края знаков для OCR
        s->set_denoise(s, 1);      // минимальный шумоподавитель, не размывает мелкий шрифт
        s->set_awb_gain(s, 1);
        s->set_wb_mode(s, 0);
        s->set_exposure_ctrl(s, 1);
        s->set_aec2(s, 1);
        s->set_gain_ctrl(s, 1);
        s->set_agc_gain(s, 0);
        s->set_gainceiling(s, (gainceiling_t)6);
        s->set_bpc(s, 1);
        s->set_wpc(s, 1);
        s->set_hmirror(s, 1);
        s->set_vflip(s, 1);
    }

    cam_ready = true;
    Serial.println("Camera OK (UXGA 1600x1200)");
    return true;
}

void camera_deinit() {
    if (!cam_ready) return;   // не инициализирована — deinit не нужен
    esp_camera_deinit();
    cam_ready = false;
    current_fb = nullptr;
}

bool camera_capture(uint8_t** buf, size_t* len) {
    if (!cam_ready) return false;

    // Кадр может быть не готов сразу — несколько попыток,
    // чтобы одно нажатие OK гарантированно давало фото
    for (int attempt = 0; attempt < 5; attempt++) {
        current_fb = esp_camera_fb_get();
        if (current_fb) {
            *buf = current_fb->buf;
            *len = current_fb->len;
            return true;
        }
        vTaskDelay(pdMS_TO_TICKS(30));
    }

    Serial.println("Camera capture failed");
    return false;
}

void camera_release() {
    if (current_fb) {
        esp_camera_fb_return(current_fb);
        current_fb = nullptr;
    }
}

bool camera_capture_after(uint8_t** buf, size_t* len, uint64_t after_ms) {
    if (!cam_ready) return false;

    camera_fb_t* fb = nullptr;
    uint64_t start_ms = millis();

    for (int i = 0; i < 30; i++) {
        camera_fb_t* f = esp_camera_fb_get();
        if (f) {
            uint64_t ts = (uint64_t)f->timestamp.tv_sec * 1000 +
                          (uint64_t)f->timestamp.tv_usec / 1000;
            bool fresh;
            if (ts > 0) {
                fresh = (ts >= after_ms);           // кадр начат после установки фокуса
            } else {
                fresh = (millis() - start_ms >= 150);  // время не ведётся — ждём период кадра
            }

            if (fb) { esp_camera_fb_return(fb); fb = nullptr; }
            if (fresh) {
                current_fb = f;
                *buf = f->buf;
                *len = f->len;
                return true;
            }
            fb = f;   // держим последний кадр как запасной, отдавая предыдущий
        }
        vTaskDelay(pdMS_TO_TICKS(25));
    }

    if (fb) {          // таймаут: возвращаем последний доступный кадр
        current_fb = fb;
        *buf = fb->buf;
        *len = fb->len;
        return true;
    }
    return false;
}

bool camera_is_ready() {
    return cam_ready;
}

void camera_set_brightness(int val) {
    if (!cam_ready) return;
    sensor_t* s = esp_camera_sensor_get();
    if (s) s->set_brightness(s, val);
}

void camera_set_focus(int pos) {
    if (!cam_ready) return;
    if (pos < 0) pos = 0;
    if (pos > 1023) pos = 1023;
    current_focus = pos;
    ov5640_set_focus(pos);
}

int camera_get_focus() {
    return current_focus;
}

#else

bool camera_init() {
    Serial.println("Camera not available without PSRAM");
    return false;
}
void camera_deinit() {}
bool camera_capture(uint8_t** buf, size_t* len) { return false; }
bool camera_capture_after(uint8_t** buf, size_t* len, uint64_t after_ms) { return false; }
void camera_release() {}
bool camera_is_ready() { return false; }
void camera_set_brightness(int val) {}
void camera_set_focus(int pos) {}
int camera_get_focus() { return 0; }

#endif

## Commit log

2026-09-19 First commit : created architecture and work command extract, other commands is plugs
    [partitions.csv]
2026-09-19 feat: README, faster buttons with repeat-fire, reduced main loop delay
    - Add README.md with project docs (hardware, structure, build instructions)
    - Reduce debounce 50ms→20ms for snappier response
    - Add repeat-fire for nav buttons (300ms delay, 80ms rate)
    - Reduce main loop delay 5ms→2ms for faster LVGL updates
    [main.cpp]
2026-09-19 fix: SD card paths — use /sdcard prefix, fix count_dir_items and navigation
    SD_MMC requires absolute paths starting with /sdcard. Previously
    current_path was just /, causing 'does not start with /' errors
    when listing SD card folders.
    - Add get_root_path(), is_at_root(), reset_to_root() helpers
    - count_dir_items now receives full path (not bare name)
    - All navigation uses correct root path for each filesystem
    - Extract go_up() and enter_dir() helper functions
2026-09-19 fix: skip mount point entries in SD/MicroFS scan
    SD_MMC.open("/") returns 'sdcard' as a directory entry, causing
    enter_dir('sdcard') which creates '/sdcard/sdcard/'.
    Now scan_directory() skips entries matching the mount point name
    ('sdcard' for SD, 'littlefs' for LittleFS). Also removed debug prints.
2026-09-19 fix: filter mount point entries regardless of current_src
    The previous filter checked current_src == SRC_SD, but count_dir_items
    is called from update_display when current_src may still be SRC_INTERNAL.
    Now 'sdcard' and 'littlefs' entries are always skipped.
2026-09-19 fix : strings handling logic in explorer app has reworked : String objects are now used instead of char ptr
    [camera_app.cpp, main.cpp]
2026-09-19 open picture in explorer has fixed
    [camera_app.cpp]
2026-09-19 fix: camera rotation via sensor hmirror/vflip, improve capture quality
    - Enable hmirror(1) + vflip(1) on OV5640 sensor — photo is now
    correctly oriented both in preview AND saved JPEG
    - Remove software rotate_scale() — no longer needed, sensor handles it
    - Fix capture decode params: was 800x1600 (wrong), now 400x300 (correct
    for scale=2)
    - Preview still uses QUARTER scale (200x150) for speed
    [camera_app.cpp, camera_driver.cpp]
2026-09-19 fix: camera_capture now sets *buf and *len from frame buffer
    camera_capture() returned true but never copied fb->buf/fb->len to
    the output parameters, causing jpegdec to decode garbage data
    (openRAM err=4).
    [camera_driver.cpp]
2026-09-19 feat: UXGA 1600x1200 capture, manual focus, brightness control
    - Resolution: UXGA (1600x1200) instead of SVGA (800x600)
    - Quality: jpeg_quality=8 (was 12, lower=better)
    - Focus: manual VCM control via OV5640 SCCB registers
    LEFT/RIGHT buttons adjust focus (0=far, 1023=near)
    - Brightness: UP/DOWN buttons (-2..+2)
    - Status bar shows current B and F values
    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
2026-09-19 perf: EIGHTH scale preview for faster decoding, larger focus step
    - Preview decodes at EIGHTH (200x150) instead of QUARTER (400x300)
    — 4x fewer pixels to decode, much smoother
    - Focus step increased 32→64 for faster adjustment
    - Reduced status bar updates during button presses
2026-09-20 feat: add Snake and 2048 games
    Snake:
    - 26x14 grid, 12px cells, canvas drawing
    - D-pad movement, OK to start/pause
    - Score tracking, high score
    - 150ms tick rate
    2048:
    - 4x4 grid, 48px cells, canvas drawing
    - Tile colors matching original game
    - Slide-merge logic with rotation trick
    - Score + best score display
    - OK to reset
    [main.cpp]
2026-09-20 feat: battery USB status indicator (no hardware changes)
    - Battery service: detects USB power via GPIO44 (VBUS detect)
    - Status bar on home screen: shows USB/BATT icon
    - Updates every 5 seconds
    - Green USB icon when charging, orange BATT when on battery
    - No ADC/voltage divider needed — USB detection only
2026-09-20 fix: battery label in header instead of separate panel
2026-09-20 fix: USB detection via Serial CDC, remove broken icon symbols
    [battery_service.cpp]
2026-09-20 feat: custom battery icon with fill bar, remove --:-- time text
    - Battery icon drawn with LVGL primitives (outline + fill bar)
    - Fill level changes based on charge percentage
    - Color: green (>50%), orange (20-50%), red (<20%), green (USB)
    - Percentage text next to icon
    - Removed '--:--' placeholder from status bar
2026-09-20 fix: real ADC battery voltage measurement
    - Reads voltage via ADC on GPIO3 with voltage divider
    - Formula: Vbat = Vadc * (R1+R2)/R2
    - LiPo curve: 4.2V=100%, 3.3V=0%
    - 4x averaging for stable readings
    - USB detected by voltage >4.5V
    - Configure BAT_PIN and BAT_DIVIDER_RATIO in battery_service.cpp
    [battery_service.cpp]
2026-09-20 fix: real ADC battery reading with debug output
    - analogRead on GPIO3 with 8x averaging
    - Prints ADC raw, Vadc, Vbat to Serial for debugging
    - If V<1V: shows actual voltage instead of '???' (no battery/divider)
    - USB detection: only if V>4.35V (above full LiPo charge)
    - User can see actual readings in Serial Monitor
    [battery_service.cpp]
2026-09-20 fix: raw ADC driver for GPIO3 battery reading
    - Uses esp_adc_cal driver directly instead of Arduino analogRead
    - gpio_reset_pin + GPIO_FLOATING before every read
    - esp_adc_cal_raw_to_voltage for calibrated millivolts
    - Serial prints raw ADC value for debugging
    [battery_service.cpp]
2026-09-20 fix: disable GPIO3 pull-up via IO_MUX register
    - Direct register write to disable PU/PD on GPIO3
    - Solves ADC reading 4095 due to internal pull-up
    - Added 5x test readings at boot for debugging
    [battery_service.cpp]
2026-09-20 fix: move battery ADC from GPIO3 to GPIO0
    GPIO3 hardwired to 3.3V on this board, always reads 4095.
    GPIO0 = ADC1_CH0, should work for voltage divider.
    [battery_service.cpp]
2026-09-20 fix: snake game uses full canvas height, no more clipping
    - ROWS 14→15 (180px grid, was 168)
    - CANVAS_H 210 (fits under 30px header)
    - OFFSET_Y centered: (210-180)/2 = 15
    - Grid now fills full screen without clipping
2026-09-20 fix: back to GPIO0 for battery ADC, snake full-screen
    - GPIO0 is the only working ADC on this board
    - GPIO3 stuck at 4095 (hardwired pull-up)
    - All other ADC1 pins used by camera/buttons/display
    - Snake game: ROWS 14→15, canvas 200→210, full screen
    [battery_service.cpp]
2026-09-20 fix: ADC breaks GPIO matrix for all ADC1 pins (GPIO0-10)
    Root cause: adc1_config_width() reconfigures GPIO matrix for ALL
    ADC1 pins, not just the one being read. This breaks buttons on
    GPIO1 (UP) and GPIO2 (DOWN) which are also ADC1 channels.
    Fix:
    - battery_init() now restores GPIO1 and GPIO2 to digital INPUT_PULLUP
    after configuring ADC1
    - battery_init() moved before input_init() in main.cpp so input_init
    sets up buttons AFTER ADC config
    [battery_service.cpp, main.cpp]
2026-09-20 fix: battery calibration 0.86 (was showing 20% at 0%)
    ADC reads ~16% high on this board. Calibration factor 0.86
    brings 3.0V (dead) to 0% and 4.2V (full) to 100%.
    [battery_service.cpp]
2026-09-21 fix: pass app icons to home screen (was nullptr)
    [main.cpp]
2026-09-21 fix: rotate saved photos in file explorer viewer
    - Add lv_image_set_rotation(900) = 90° CW in image viewer
    - Saved JPEG matches camera preview orientation
    - Also inject EXIF orientation tag for external viewers
    [camera_app.cpp]
2026-09-22 fix: saved photo now matches preview orientation
    Root cause: scale_image() in camera preview transposes the frame
    (swapped X/Y axes) because the sensor is physically rotated, while
    the saved JPEG was written raw — so saved photos appeared mirrored
    and rotated -90° vs preview.
    - save_photo(): decode full-res JPEG to RGB565, transpose (same
    transform as preview), re-encode with JPEGENC -> file itself is
    correct for any viewer (local, PC, AI)
    - jpeg_decoder: add optional transpose mode (full resolution)
    - add bitbank2/JPEGENC library
    - revert EXIF orientation hack and image-viewer rotation hack
    [camera_app.cpp, jpeg_decoder.cpp]
2026-09-22 UX: 1:1 preview/photo match, one-press capture, 'Shot' toast
    - Preview: scale_image now letterboxes with correct aspect ratio
    (was stretched to 320x204) — matches saved photo 1:1
    - Image viewer: fit photo to screen (was showing 1200x1600 at
    native size = only a corner visible = 'zoomed in')
    - Capture: camera driver retries fb_get up to 5x so one OK press
    always yields a photo
    - Toast: 'Shot' banner appears instantly on OK press, updates
    with file size (or error), auto-hides after 2s
    - New lang string camera_error (RU/EN)
    [camera_app.cpp, camera_driver.cpp]
2026-09-22 Add Tetris and Flappy games
    - Tetris: 10x20 field, ghost piece, next preview, wall kicks, levels/speedup, line clear scoring
    - Flappy: pipe physics, instant flap on OK press (forwarded BTN_EVENT_PRESSED), best score
    - main: forward BTN_EVENT_PRESSED to apps (others filter CLICKED)
    - file_explorer: filter non-click events (consistency fix)
    - README: games listed
    [main.cpp]
2026-09-22 Optimize saved JPEG for maximum text/OCR readability
    - Sensor: jpeg_quality 8 -> 4 (finer source detail), contrast 1 -> 2,
    sharpness 2 -> 3 (max, crisper glyph edges), denoise stays at
    minimum so fine font strokes aren't smeared
    - Re-encode: JPEGE_Q_HIGH/420 -> JPEGE_Q_BEST/444 (no chroma
    subsampling, highest quality tables)
    - Free-space check headroom raised (output can be much larger now)
    - Detect short writes during encode; delete partial file on failure
    so a full disk never leaves a broken JPEG
    - README: note text/OCR optimization
    [camera_app.cpp, camera_driver.cpp]
2026-09-22 Камера: автофокус (CDAF), превью во весь экран с режимами во всю ширину/весь кадр
    - Автофокус: контрастный перебор VCM (грубый 8 позиций + точная подстройка),
    метрика — сумма градиентов яркости на кадре 1/4 UXGA. Запуск при открытии
    и перед каждым снимком (плашка «Автофокус...» сразу при нажатии OK).
    - camera_capture_after(): свежий кадр по timestamp (fallback — ожидание
    периода кадра), чтобы метрика не брала кад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
2026-09-22 Камера: декод превью вынесен в отдельную задачу (core 0) — UI не лагает
    Причина лагов: декод 1/4 UXGA (~100+ мс) шёл в потоке LVGL — каждый тик
    таймера блокировал обработку кнопок и перерисовку.
    - Воркер cam_prev (FreeRTOS, core 0, 8KB): декод JPEG + scale_image в
    второй canvas-буфер; LVGL только выдаёт кадр (с fb камеры) и показывает
    готовый результат сменой указателя буфера (без копирования).
    - Синхронизация через portMUX (job_re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
2026-09-22 wifi_service (SoftAP CSCAM) + ai_link (HTTP-мост к ИИ) + экран «ИИ»
    - wifi_service: SoftAP WPA2 192.168.4.1, NVS-переключатель в Настройках,
    иконка WiFi в статус-баре учитывает AP-режим
    - ai_link: HTTP-сервер в отдельной задаче (/api/state, /api/photo,
    /api/answer, /), очередь фото из save_photo, текст ответа 4KB,
    LVGL-таймер автооткрытия экрана «ИИ»
    - экран «ИИ» (8-е приложение): состояние цепочки + скроллируемый ответ
    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
2026-09-22 phone/android: CamLink — Android-мост к ИИ (Kotlin, без зависимостей)
    - WifiNetworkSpecifier: локальное подключение к SoftAP CSCAM,
    телефон остаётся на мобильном интернете для API ИИ
    - цепочка: /api/state → /api/photo → resize ≤1568 → Gemini/OpenAI vision
    → POST /api/answer (X-Id) → ответ на экране устройства
    - настройки: провайдер, API-ключ, промпт, SSID/пароль
    - программный UI (без XML-лейаутов), сборка в Android Studio, minSdk 29
    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
2026-09-24 fix: boot-loop с чёрным экраном — server.begin() вызывался при выключенном WiFi
    Причина: wifi_service мог не поднять AP (выключен в настройках, NVS),
    а ai_link_init() всё равно звал server.begin() → lwIP не инициализирован →
    assert «tcpip_send_msg_wait_sem: Invalid mbox» → reboot-луп до loop(),
    экран оставался чёрным (LVGL не запускался).
    - ai_link_ensure_server(): begin() только при ai_ready && wifi_service_running();
    вызывается из ai_link_init и из wifi_service_start (после softAP — lwIP готов)
    - HTTP-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
    [ai_link.cpp, main.cpp, wifi_service.cpp]
2026-09-24 chat: history store + chat-style ИИ screen + settings scroll fix
    - ai_link: 16-entry ring history (question/answer/photo events) persisted to
    LittleFS /ai_chat.log, new endpoints POST /api/chat (X-Question) and
    GET /api/history, urldecode + JSON escape, UTF-8 safe truncation
    - ai_answer_app: rebuilt as chat feed (bubbles, flex rows, UP/DOWN page
    scroll, rebuild on history seq change, auto-scroll to latest)
    - settings: scroll selected row into view on UP/DOWN navigation, content
    above 240px now scrollable
    - lang: add ai_you string (RU Вы / EN Me)
    [ai_link.cpp]
2026-09-24 chat on device: phone is AI bridge only (input + status)
    - ai_link: type-2 pending question (POST /api/question) with '…' bubble,
    answer fills it in place (hist_fill_last_answer + file rewrite);
    auto-open screen on question/answer only, not on photo events;
    /api/chat and /api/answer both fill pending question first
    - phone: chat ListView removed — keyboard input + attach + status/log only;
    question pushed to device immediately, then AI call, then answer;
    fix: Network.openConnection(url) instead of nonexistent
    HttpURLConnection.socketFactory setter (app never compiled before)
    - README/TODO: chat architecture and API table updated
    [MainActivity.kt, ai_link.cpp]
2026-09-24 ИИ app: Сфоткать/Отправить buttons + settings scroll fix (real this time)
    - ai_answer_app: bottom action bar (LEFT/RIGHT select, OK press):
    «Сфоткать» captures right in chat via new camera_app_capture_headless
    (init camera on demand + CDAF + save_photo, stage toasts with refr_now),
    «Отправить» bumps send_seq -> phone polls /api/state and auto-runs
    photo -> AI -> answer; toasts for no-photo/waiting/errors
    - settings: section now has FIXED height (240-52) with its own scrollbar —
    content really overflows, scroll_to_view pulls selected row into view
    - ai_link: ai_link_request_send()/send_seq, "send" field in /api/state
    - phone: 2s poll of /api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
    [MainActivity.kt, ai_link.cpp, camera_app.cpp]
2026-09-24 fix: Сфоткать reboot (background capture task, 16KB/core1) + Android CHANGE_NETWORK_STATE crash
    [MainActivity.kt, camera_app.cpp, main.cpp]
2026-09-24 camlink: detect EPERM storm (device rebooting under load) and hint power issue
    [MainActivity.kt]
2026-09-24 camlink: EPERM forensics — log onAvailable/onLost timing to separate dead-link vs bind-denied
2026-09-24 Файловый менеджер ESP, быстрый AF, VPN-детект EPERM, чистый лог телефона
    - ai_link: файловое API /api/fs (список), /api/file GET/POST/DELETE;
    виртуальные пути /flash (LittleFS) и /sd (SD /sdcard), загрузка потоково
    - camera_app: быстрый AF для «Сфоткать» (окно ±64 вокруг прошлой позиции,
    полный проход только при пике на краю) — снимок без вечного перебора
    - CamLink: экран «📁» FileActivity — навигация, скачивание в Загрузки,
    загрузка на ESP, уд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
2026-10-02 Fix: abort в hist_add (localtime внутри critical) + часы от телефона
    - Корень падения «abort() ... lock_acquire_generic locks.c:139»:
    localtime() брал newlib-замок ВНУТРИ portENTER_CRITICAL — там прерывания
    замаскированы, newlib считает себя в прерывании и abort'ует
    («recursive mutex in ISR context»). Оба бэкстрейса (h_question и
    save_photo→notify) шли через hist_add.
    - Новый services/time_service: время/дата без localtime/gmtime
    (алгоритм Hinnant, только arithmetic), часы заводятся заголовками
    X-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
    [MainActivity.kt, ai_link.cpp, camera_app.cpp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]
2026-10-02 fix: управление в приложениях мертво — dangling в app_registry_get_running
    a65647b случайно заменил индексный цикл на for (auto app : apps) и
    return &app — адрес локальной копии структуры. main.cpp читал мусор из
    вернувшегося стека: app->on_button обычно оказывался nullptr и события
    молча отбрасывались. Симптом: во всех приложениях кнопки не работают,
    но OK-долгое (обрабатывается в main до диспетчеризации) и домашний
    экран работают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
2026-10-02 Мгновенный снимок: ensure_focus вместо полного AF, тёплая камера 60 с, «Снято» только после экспозиции
    - ensure_focus(): сначала сверка резкости с последним AF (1 кадр),
    затем локальный пик ±64 (3 кадра, независимо от содержимого сцены),
    и только при провале — настоящий перебор. Первый кадр после
    включения — всегда полный AF (базы ещё нет).
    - Камера не гасится после снимка/закрытия приложения: 60 с тёпл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
2026-10-02 CamLink: прокси для ИИ (порт Happ), автоповтор пустых ответов, фоновый мост
    - «Прокси для ИИ» в настройках: запросы к API идут на локальный порт Happ
    (Разрешить LAN-подключения), локал с устройством всегда напрямую
    - ИИ: аккуратный разбор content (строка/части/null) + до 3 повторов —
    роутер openrouter/free при мусорном ответе выбирает другую модель
    - BridgeService (foreground, connectedDevice): WifiLock + WakeLock,
    опрос /api/state и вызовы И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
2026-10-02 Added case 3d model in repo
    [CheatSheat2Case.stl]
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
